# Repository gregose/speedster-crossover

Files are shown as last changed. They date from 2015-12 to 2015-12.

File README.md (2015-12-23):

# Speedster Crossover

Crossover PCB layout for [Paul Carmody's Speedster speakers](https://sites.google.com/site/undefinition/speedster). Designed with V-cut stackable boards for high and low-pass circuits.

### Render

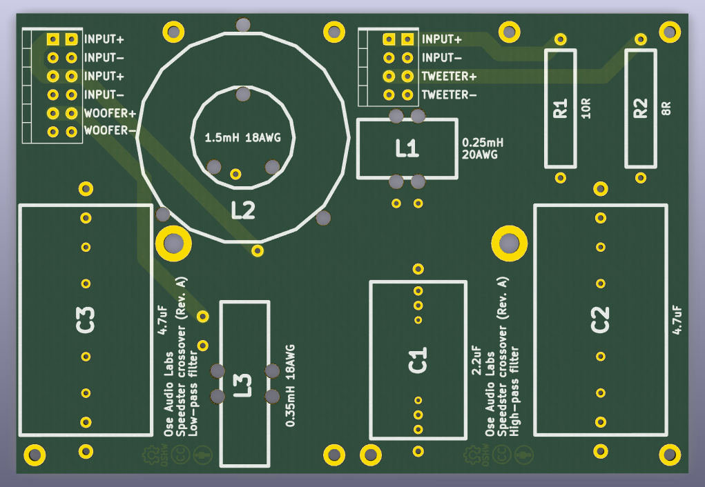
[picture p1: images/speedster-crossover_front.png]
Front render

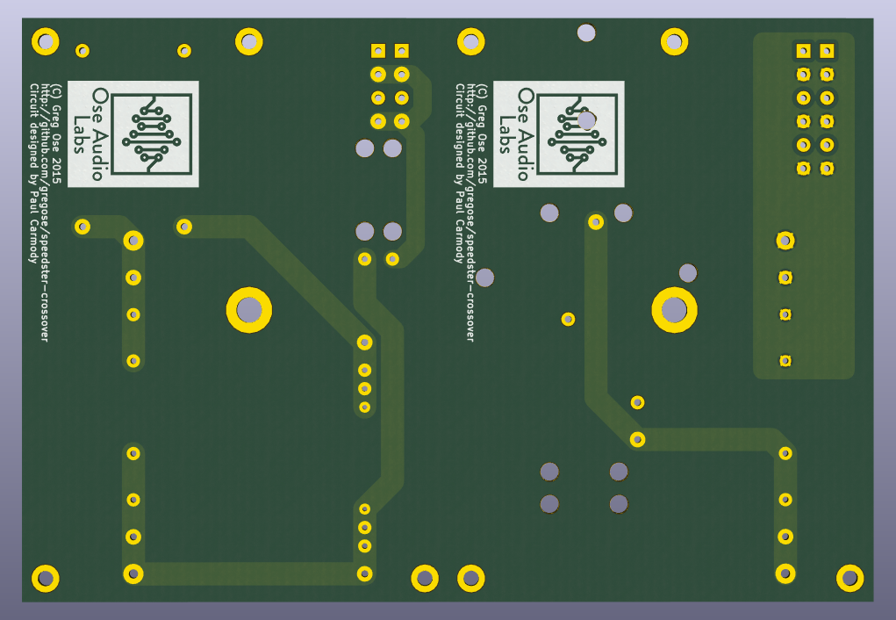
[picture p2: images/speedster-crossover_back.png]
Back render


### Schematic

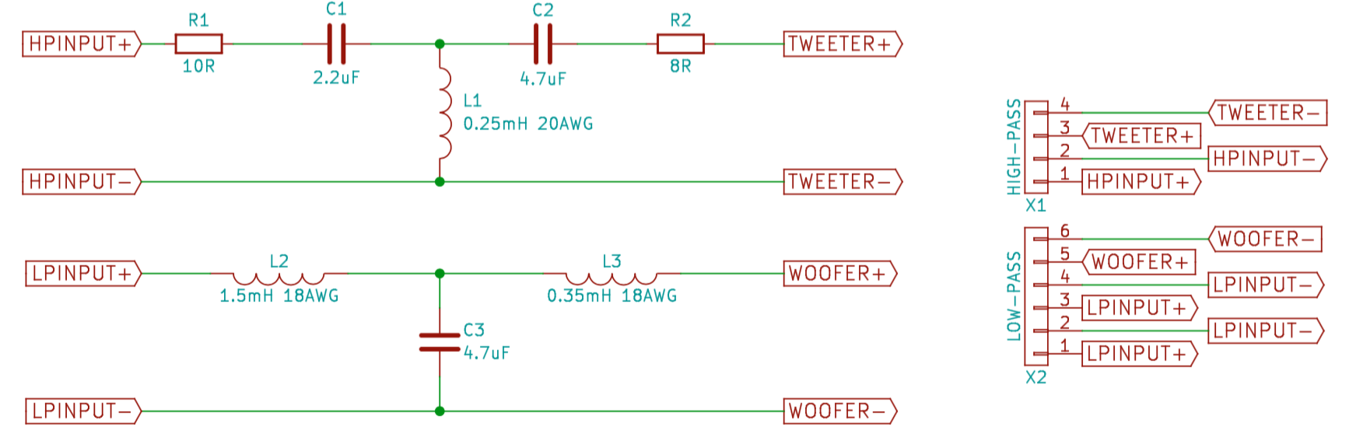
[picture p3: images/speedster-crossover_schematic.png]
Schematic


### BOM

The layout was designed for the following components. Extra pads have been added to allow the use of physically smaller capacitors. Additional pins have been added to X1 and X2 to support the use of through-hole quick disconnects.

Ref | Component | Link 
----| --------- | -------------
R1  | Vishay Mills MRA-12 10R | http://www.digikey.com/product-search/en?mpart=MRA-1210R00FE12&vendor=541
R2  | Vishay Mills MRA-12 8R | http://www.digikey.com/product-search/en?mpart=MRA-128R000FE12&vendor=541
C1  | AUDYN CAP PLUS MKP 2.20 MF/ 800 V 2% AXIAL 43X25 | https://www.intertechnik.com/Shop/Cross-over-parts/Capacitors/Audyn-Cap-Plus/_PLUS22008_1768,en,280,46735
C2  | AUDYN CAP PLUS MKP 4.70 MF/ 800 V 2% AXIAL 63X35 | https://www.intertechnik.com/Shop/Cross-over-parts/Capacitors/Audyn-Cap-Plus/_PLUS47008_1768,en,280,46738
C3  | AUDYN CAP PLUS MKP 4.70 MF/ 800 V 2% AXIAL 63X35 | https://www.intertechnik.com/Shop/Cross-over-parts/Capacitors/Audyn-Cap-Plus/_PLUS47008_1768,en,280,46738
L1  | Meniscus Audio .25mH, Perfect Layer 20ga. | http://meniscusaudio.com/025mh-20ga-p-597.html
L2  | Meniscus Audio 1.5mH, Layer  Wound 18ga. | http://meniscusaudio.com/150mh-18-ga-p-638.html
L3  | Meniscus Audio .35mH, Layer  Wound 18ga. | http://meniscusaudio.com/035mh-18-ga-p-622.html
X1  | Phoenix Contact 1730418 (CONN TERM BLOCK 4POS 5.08MM) | http://www.digikey.com/product-search/en?mpart=1730418&vendor=277
X2  | Phoenix Contact 1730434 (CONN TERM BLOCK 6POS 5.08MM) | http://www.digikey.com/product-search/en?mpart=1730434&vendor=277
X1/2 Alt. | PCB quick disconnect terminal | http://www.mcmaster.com/#7956k5/=10cwxu4

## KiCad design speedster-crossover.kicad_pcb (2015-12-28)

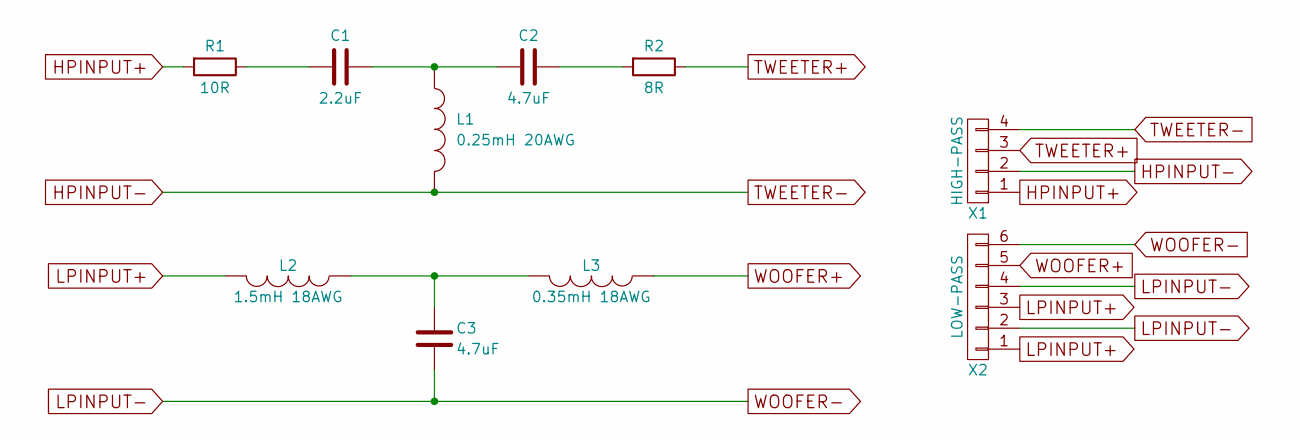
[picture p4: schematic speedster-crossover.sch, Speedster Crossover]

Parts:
C1: 2.2uF; OAL_cap_2.2
C2, C3: 4.7uF; OAL_cap_4.7
L1: 0.25mH 20AWG; OAL_inductor_0.25-20AWG-Vertical
L2: 1.5mH 18AWG; OAL_inductor_1.5-18AWG
L3: 0.35mH 18AWG; OAL_inductor_0.35-18AWG-Vertical
R1: 10R; OAL_resistor_MRA12
R2: 8R; OAL_resistor_MRA12
X1: HIGH-PASS; OAL_pheonix_mkds_2.5-4pos
X2: LOW-PASS; OAL_pheonix_mkds_2.5-6pos

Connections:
HPINPUT+: R1.2, X1.1
HPINPUT-: L1.2, X1.2, X1.4
LPINPUT+: L2.2, X2.1, X2.3
LPINPUT-: C3.2, X2.2, X2.4, X2.6
unnamed: C1.1, C2.1, L1.1
unnamed: C1.2, R1.1
unnamed: C2.2, R2.2
unnamed: C3.1, L2.1, L3.2
TWEETER+: R2.1, X1.3
WOOFER+: L3.1, X2.5

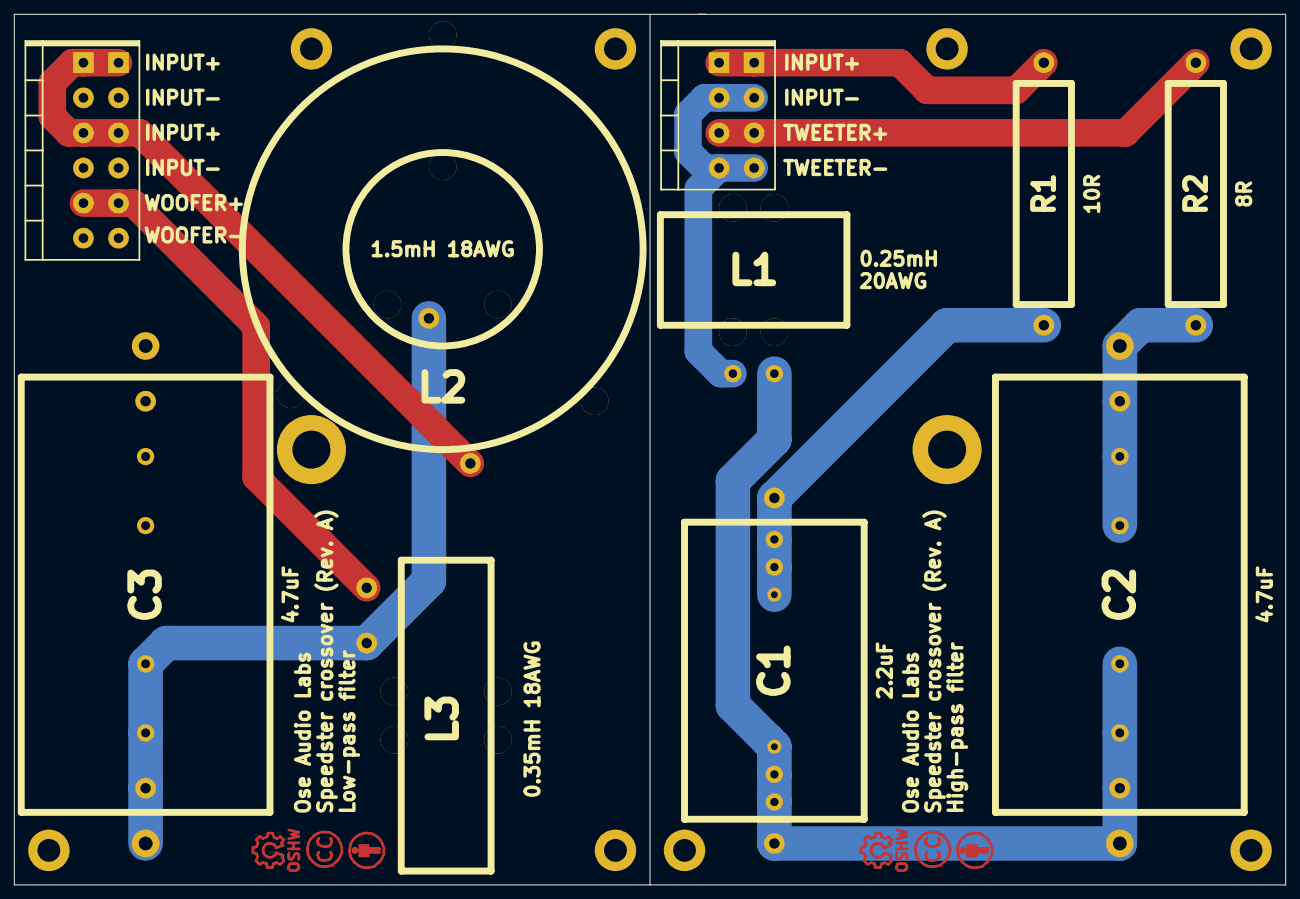
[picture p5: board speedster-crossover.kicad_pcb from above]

Board: 2 copper layers, 184.0 x 126.0 mm, 10 parts (0 on the bottom side), 10 nets.

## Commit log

2015-12-17 initial layout
    [speedster-crossover-B.Cu.gbl, speedster-crossover-B.Mask.gbs, speedster-crossover-B.SilkS.gbo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]
2015-12-17 add schematic image
    [speedster-crossover.sch]
2015-12-23 Updates to layout
    - smaller L3 footprint
    - tighter C1 lead spacing
    - alternative quick-disconnect pins for X1/2
    (http://www.mcmaster.com/#7956k5/=10cwxu4)
    - plated mounting holes
    [speedster-crossover-B.Cu.gbl, speedster-crossover-B.Mask.gbs, speedster-crossover-B.SilkS.gbo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]
2015-12-23 Mention PCB quick disconnect alts
2015-12-23 Fine tune some lead spacing, back silkscreen logo
    [speedster-crossover.kicad_pcb]
2015-12-26 add license, update logos
    [speedster-crossover.kicad_pcb]
2015-12-28 final tweaks before fab
    [speedster-crossover-B.Cu.gbl, speedster-crossover-B.Mask.gbs, speedster-crossover-B.SilkS.gbo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]
